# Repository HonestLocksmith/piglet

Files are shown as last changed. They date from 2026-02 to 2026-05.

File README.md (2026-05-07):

# Piglet Wardriver

**Piglet** is an open-source ESP32-based wardriving platform that scans nearby Wi-Fi networks, records GPS position, saves WiGLE-compatible CSV logs to SD, and provides a real-time web UI for control, uploads, and device status.

Designed for **Seeed XIAO ESP32-S3, ESP32-C5, and ESP32-C6**, Piglet focuses on:

- Reliable scanning while in motion  
- Clean WiGLE-ready data collection  
- Simple field deployment  
- Fully hackable open firmware

## Features

- 2.4 GHz Wi-Fi scanning  
- 5 GHz scanning on ESP32-C5 hardware  
- GPS position, heading, and speed logging  
- SD card logging in WiGLE CSV format  
- Web UI for:
  - Start / stop scanning  
  - Upload logs to WiGLE  
  - View device status  
  - Manage SD files  
  - Edit configuration  
- OLED live status display  
- Optional battery monitoring (board dependent)  
- Automatic STA connect with AP fallback  
- Optimized for mobile wardriving or warWalking!
- **ESP-Now Mesh Node mode** — pair with a coordinator device for multi-node wardriving
- **Mesh auto-start on boot** — configure `meshModeOnBoot` to automatically enter Core or Node mode after uploads complete, bypassing the AP window

## ESP-Now Mesh Network Node Mode

Piglet includes a built-in **Mesh Node mode** that lets it act as a wireless wardriving node alongside a compatible coordinator device. In this mode, Piglet scans Wi-Fi networks and forwards results over ESP-Now — no SD card or GPS fix required on Piglet itself. The coordinator handles GPS stamping and data logging.

### Compatible Coordinator Devices

- **Biscuit Pro** by [Hedge / Biscuit Shop](https://biscuitshop.us)
- **JCMK C5 Wardriver** by JustCallMeKoko

### How to Use

1. Power on your coordinator device (Biscuit Pro or JCMK C5 Wardriver)
2. On Piglet, press the button to cycle pages until you reach **Mesh Node** (the last page after the pig animation)
3. Piglet automatically searches for a coordinator on ESP-Now channel 6
4. Once connected, it receives a channel range assignment and begins forwarding scan data
5. Press the button again to exit Mesh Node mode and return to normal wardriving

### Mesh Node Display

While in Mesh Node mode the OLED shows:
- Link status (Searching / Core linked)
- Coordinator MAC address
- Assigned channel range
- Total networks discovered
- Records forwarded to the coordinator

> **Note:** Entering Mesh Node mode suspends normal WiGLE CSV logging. All data is sent live to the coordinator. Exiting the page restores normal scanning automatically.

### Auto-Start Mesh Mode on Boot

Set `meshModeOnBoot` in `/wardriver.cfg` to automatically enter mesh mode after boot uploads are complete, without needing to navigate pages manually:

| Value | Behaviour |
|---|---|
| `none` | Normal wardriving (default) |
| `core` | Enters Mesh Core mode — acts as coordinator, logs records from nodes |
| `node` | Enters Mesh Node mode — forwards scan results to a Core |

When `core` or `node` is set the SoftAP window is **skipped entirely** (ESP-Now owns the WiFi stack and the AP would be non-functional). The device goes straight from boot uploads to the mesh page. Set via the web UI **Mesh Mode On Boot** dropdown or directly in `/wardriver.cfg`.

## T-Dongle C5 Variant

A standalone firmware port is available for the **LilyGo T-Dongle C5** in the `TDongleC5_Piglet/` folder. This variant is a self-contained single-file sketch with its own display driver, LED control, and web UI — no external OLED required.

**Hardware:** LilyGo T-Dongle C5 (ESP32-C5, built-in ST7735 0.96" TFT, APA102 LED, TF card slot)

**Additional GPS:** Connect any UART GPS module via the Qwiic/JST connector (RX=GPIO12, TX=GPIO11)

**Pages:** Status · Networks · Navigation · Pig animation · Mesh Node

### T-Dongle C5 Required Libraries

Install via Arduino Library Manager (`Sketch → Include Library → Manage Libraries`):

| Library | Author |
|---|---|
| Adafruit ST7735 and ST7789 Library | Adafruit |
| Adafruit GFX Library | Adafruit |
| Adafruit BusIO | Adafruit |
| TinyGPSPlus | Mikal Hart |
| ArduinoJson | Benoit Blanchon |

All networking, SPI, SD, ESP-Now, and ESP-IDF headers are included in the ESP32 Arduino core — no separate install needed.

**Board setup:** Add `https://espressif.github.io/arduino-esp32/package_esp32_dev_index.json` to Additional Boards Manager URLs, install **esp32 by Espressif v3.x or later**, and select **ESP32C5 Dev Module**.

## Supported Hardware

### Microcontroller Boards

- Seeed XIAO ESP32-S3  
- Seeed XIAO ESP32-C5 *(required for 5 GHz scanning)*  
- Seeed XIAO ESP32-C6  
- LilyGo T-Dongle C5 *(standalone variant — see above)*  

### Required Peripherals

- I2C GPS module (ATGM336H)
- 128×64 SSD1306 OLED display (I2C)
- SPI SD card module
- Optional LiPo battery connected to XIAO battery inputs

### Peripheral Sourcing  
You can get everything on Amazon but its pricey.  if you dont mind waiting on aliexpress heres the build list.
- Xiao-C5 - 7$ [SeedStudio](https://www.seeedstudio.com/Seeed-Studio-XIAO-ESP32C5-p-6609.html)
- SSD1306 128x63 OLED - $2 [aliexpress](https://www.aliexpress.us/item/3256805954920554.html)
- ATGM-336h - $3.39 [aliexpress](https://www.aliexpress.us/item/3256809330278648.html)
- SD-Card Module - $1.33 [aliexpress](https://www.aliexpress.us/item/3256808167816573.html)
- User Button - $0.41 [Item:CS1211 From Digikey](https://www.digikey.com/en/products/detail/cit-relay-and-switch/CS1211/16607858)

$14 if you wanted to breadboard it yourself.

## Wiring / Pinouts

Pin mappings are automatically selected by firmware.

### XIAO ESP32-S3

| Function | Pin |
|---|-----|
| I2C SDA | GPIO 5 |
| I2C SCL | GPIO 6 |
| GPS RX | GPIO 4 |
| GPS TX | GPIO 7 |
| Button | GPIO 1 |
| SD CS | GPIO 2 |
| SD MOSI | GPIO 10 |
| SD MISO | GPIO 9 |
| SD SCK | GPIO 8 |

### XIAO ESP32-C6 / ESP32-C5

| Function | Pin |
|---|-----|
| I2C SDA | GPIO 23 |
| I2C SCL | GPIO 24 |
| GPS RX | GPIO 12 |
| GPS TX | GPIO 11 |
| Button | GPIO 0 |
| SD CS | GPIO 7 |
| SD MOSI | GPIO 10 |
| SD MISO | GPIO 9 |
| SD SCK | GPIO 8 |

**Note:** Only the ESP32-C5 supports 5 GHz Wi-Fi scanning.

## 3D Printed Cases

Print-ready STL files are available in the `Case Files/` directory. These cases are designed specifically for the Piglet PCB and module stack.

### 👏 Case Design by Bread — Breadbox Systems

The Piglet case was designed by **Bread** at [Breadbox Systems](https://breadboxsystems.com). If you print one, please take a moment to **like and boost the design on MakerWorld** — it helps the creator and makes the design easier for others to find.

> **[🖨️ Print the Piglet Wardriver Case on MakerWorld →](https://makerworld.com/en/models/2708429-piglet-wardriver-case#profileId-3000037)**

| File | Description |
|---|---|
| `Piglet Face.STL` | Front panel / lid |
| `Piglet Butt.STL` | Rear enclosure |
| `Piglet Butt with SMA hole.STL` | Rear enclosure with external antenna cutout |
| `Piglet Midboard.STL` | Internal standoff / mid-layer |
| `Piglet Features.stl` | Feature plate / accessory mount |

For the **T-Dongle C5** variant, GPS antenna mount STLs are included in `TDongleC5_Piglet/GPS STL/`.

> Print with standard PLA or PETG. No supports required on most parts. Recommend 0.2 mm layer height, 3 perimeters.

## PCB Design

Piglet includes custom PCB designs for compact, production-ready builds. KiCad project files and Gerber production files are available in the `PCB Files/` directory.

### PCB Images

| Board Front | Board Back | Board Close-up |
|---|---|---|
| Board1 | Board2 | Board3 |

### Assembled Piglet

| Module Arrangement | Front View | Back View |
|---|---|---|
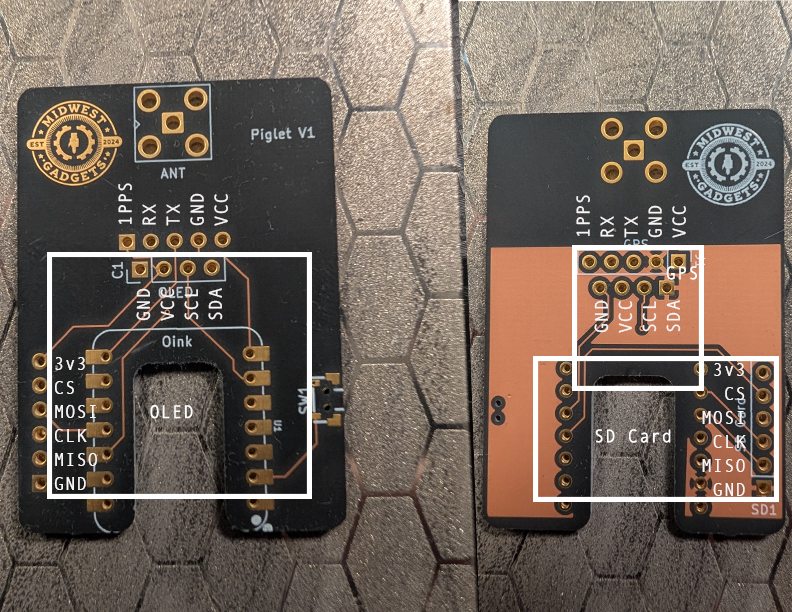
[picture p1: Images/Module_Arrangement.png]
Module Arrangement
|  | Built Piglet Front | Built Piglet Back |

**Assembly Note:** When stacking modules, apply **Kapton tape** between components to prevent electrical shorts. Pay special attention to exposed pins and solder joints that may contact adjacent modules.

## First Time Run Initialization

The Wardriver functions using a config file located on the root of a FAT32-formatted SD card. On first boot the device will start its own access point (`Piglet-WARDRIVE` / `wardrive1234`) so you can connect and fill in your settings via the web interface — or you can place the config file on the SD card manually before powering on.

**AP Timer & Keep-Alive**

The SoftAP runs for **60 seconds** by default. About **30 seconds before** that window expires, the WebUI shows a *"Stay in WebUI?"* prompt — clicking **Stay** extends the window to a **5 minute** rolling timer so you have room to actually use the WebUI. The same prompt re-appears 30 seconds before the 5 minute timer expires; clicking Stay again resets it.

- **Stay** — extends (or re-extends) the window to 5 minutes.
- **Start Scanning Now** — closes the AP immediately and begins wardriving.
- **Ignored / browser closed** — timer runs out, AP closes, scanning starts.

The OLED shows the live countdown (`AP: 192.168.4.1 60s` initially, `m:ss` once extended). Once your home Wi-Fi is configured, the device will connect to it on subsequent boots and the WebUI is reachable on the STA IP shown on the OLED — the AP only comes up if STA fails.

**Location:** `/wardriver.cfg` on the SD card root

A sample config file is included in `Arduino Files/Piglet/wardriver.cfg`. The full default config with all available keys is shown below:

```ini
# ============================================================
# Piglet Wardriver Configuration
# Format: key=value
# Lines starting with # are comments and ignored.
# ============================================================

# ------------------------------------------------------------
# WiGLE Upload
# ------------------------------------------------------------
# Use only the "Encoded for Use" token from wigle.net/account
# Leave empty to disable WiGLE uploads.

wigleBasicToken=EnterWigleTokenHere

# ------------------------------------------------------------
# WDGoWars
# ------------------------------------------------------------
# Get your API key at: https://wdgwars.pl/profile/
# Leave empty to disable WDGoWars uploads.

wdgwarsApiKey=EnterWDGoWarsAPIKeyHere

# ------------------------------------------------------------
# Max Automatic Uploads at Boot
# ------------------------------------------------------------
# -1 = Upload ALL pending files every boot
#  0 = Disabled — no auto-upload at boot (use web UI manually)
# 1+ = Upload up to N files per boot

maxBootUploads=-1

# ------------------------------------------------------------
# Device Name (optional)
# ------------------------------------------------------------
# A short label for this device. Used in WiGLE CSV filenames
# and in the WiGLE upload header so you can tell devices apart.
# Spaces become underscores. Max 20 characters.
# Leave empty to use the default (no prefix).

deviceName=

# ------------------------------------------------------------
# Home Wi-Fi (STA mode)
# ------------------------------------------------------------
# If provided, device connects on boot.
# If connection fails, falls back to SoftAP for 60 seconds
# (can be extended via the "Stay in WebUI?" prompt that appears
# ~30 s before the timer expires).

homeSsid=EnterWifiHere
homePsk=EnterWifiPasswordHere

# ------------------------------------------------------------
# Wardriver Access Point (SoftAP fallback)
# ------------------------------------------------------------
# SSID and password for the temporary config AP.
# Password must be 8+ characters or AP becomes open.

wardriverSsid=Piglet-WARDRIVE
wardriverPsk=wardrive1234

# ------------------------------------------------------------
# GPS Settings
# ------------------------------------------------------------
# UART baud rate for the GPS module.
# Common values: 9600, 38400, 115200

gpsBaud=9600

# ------------------------------------------------------------
# Wi-Fi Scan Mode
# ------------------------------------------------------------
# aggressive  — scans every ~3 seconds using async mode (faster, more power)
# powersaving — scans every ~12 seconds (slower, less power)

scanMode=aggressive

# ------------------------------------------------------------
# Speed Units (display only)
# ------------------------------------------------------------
# kmh = kilometers per hour
# mph = miles per hour

speedUnits=mph

# ------------------------------------------------------------
# Battery Test
# ------------------------------------------------------------
# true = logs elapsed time on battery to /battery_test.csv
# false = disabled

batteryTest=false

# ------------------------------------------------------------
# Mesh Mode On Boot
# ------------------------------------------------------------
# Automatically enter ESP-Now mesh mode after boot uploads complete.
# Bypasses the SoftAP window and jumps directly to the mesh page.
#
#   none = Normal wardriving mode (default)
#   core = Start as Mesh Core (coordinator) — logs data from nodes
#   node = Start as Mesh Node — forwards scan results to a Core
#
# Requires a compatible coordinator (Biscuit Pro, JCMK C5 Wardriver)
# when using node mode.

meshModeOnBoot=none
```

## Button Functions

### Press Types

| Press | Timing | Action |
|---|---|---|
| **Single press** | Quick tap | Advance to next page |
| **Double press** | Two taps within 350 ms | Toggle scan pause *(Status page only)* |
| **Long press** | Hold ≥ 2 seconds | Enter deep sleep |
| **Single press** *(while sleeping)* | Any | Wake from deep sleep / reboot |

### Pages (Single Press cycles through these)

| Page | Name | What it Shows | Scanning |
|---|---|---|---|
| 0 | **Status** | Scan state, SD, GPS fix, WiFi, network counts, speed, IP, upload status | ✅ Active |
| 1 | **Networks** | Large display of 2.4 GHz, 5 GHz, and total network counts | ✅ Active |
| 2 | **Navigation** | Compass arrow, heading direction, current speed | ✅ Active |
| 3 | **Paused** | Pause icon — scanning fully stopped | ❌ Paused |
| 4 | **Pig** | Walking pig animation 🐷 | ✅ Active |
| 5 | **Mesh Node** | ESP-Now link state, coordinator MAC, channel range, Found/Sent counts | ↔ Forwarded via ESP-Now |

### Double Press — Status Page Only

When on the **Status page**, double-pressing toggles a scan pause without leaving the page. Useful for a quick stop without navigating to the Pause page.

- **Double press →** Scanning paused on status page
- **Double press again →** Scanning resumed
- **Single press (page change) →** Pause automatically cleared when leaving page 0

### Long Press — Deep Sleep

Hold the button for **2 seconds** from any page:
- Active log file is flushed and closed before sleeping
- OLED displays `Sleep...` then powers off
- A single button press wakes the device (full reboot)

### Mesh Node Page

Entering **page 5** automatically starts ESP-Now node mode. Leaving it (single press to advance) automatically restores normal wardriving. See the [ESP-Now Mesh Network Node Mode](#esp-now-mesh-network-node-mode) section above for details.

## Building Firmware

### Requirements

- **Arduino IDE 2.x** or **PlatformIO**
- **Arduino-ESP32 core** v3.0.0 or later

### Required Libraries — XIAO Variant (S3 / C5 / C6)

Install via Arduino Library Manager (`Sketch → Include Library → Manage Libraries`):

| Library | Author | Notes |
|---|---|---|
| TinyGPSPlus | Mikal Hart | GPS NMEA parsing |
| Adafruit GFX Library | Adafruit | Graphics dependency |
| Adafruit SSD1306 | Adafruit | OLED display driver |
| Adafruit BusIO | Adafruit | Required by SSD1306 |
| ArduinoJson | Benoit Blanchon | v6.x or v7.x |

All other headers (`WiFi`, `WebServer`, `WiFiClientSecure`, `HTTPClient`, `SD`, `SPI`, `Wire`, `esp_now.h`, `esp_wifi.h`) are included in the ESP32 Arduino core — no separate install needed.

### Required Libraries — T-Dongle C5 Variant

Install via Arduino Library Manager:

| Library | Author | Notes |
|---|---|---|
| Adafruit ST7735 and ST7789 Library | Adafruit | TFT display driver |
| Adafruit GFX Library | Adafruit | Graphics dependency |
| Adafruit BusIO | Adafruit | Required by ST7735 |
| TinyGPSPlus | Mikal Hart | GPS NMEA parsing |
| ArduinoJson | Benoit Blanchon | v6.x or v7.x |

All networking, SPI, SD, ESP-Now, and ESP-IDF headers are built into the ESP32 core.

### Flash Steps

1. Select the correct **XIAO ESP32 board** variant (S3, C5, or C6)
2. **CRITICAL:** Enable **PSRAM** (required for TLS/HTTPS uploads)
   - Tools → PSRAM → **OPI PSRAM** (C5/C6) or **QSPI PSRAM** (S3)
3. Use a **large app partition scheme** → **Huge APP (3MB No OTA/1MB SPIFFS)**
4. Upload firmware  
5. Insert **FAT32-formatted SD card**  
6. Add `/wardriver.cfg` to SD card root with your WiGLE API key and WiFi credentials
7. Restart device with RST button or power cycle

## License

Creative Commons Attribution-NonCommercial 4.0 (CC BY-NC 4.0)

You may:

- Use  
- Modify  
- Share  

You may **not** use this project for commercial purposes.

https://creativecommons.org/licenses/by-nc/4.0/

---

Created by **Midwewest Gadgets LLC**

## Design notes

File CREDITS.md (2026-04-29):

# Credits & Attributions

Piglet Wardriver is licensed under [CC BY-NC-SA 4.0](LICENSE).  
The following third-party work, protocols, and contributions are acknowledged below.

---

## ESP-Now Mesh Protocol

**Project:** ESP32 Dual Band Wardriver  
**Author:** JustCallMeKoko ([@justcallmekoko](https://github.com/justcallmekoko))  
**Repository:** https://github.com/justcallmekoko/ESP32DualBandWardriver

Piglet's **Mesh Node mode** (page 5 on XIAO, page 4 on T-Dongle C5) implements a
wire-compatible version of the JCMK ESP-Now Core/Node protocol. This allows Piglet
to act as a scan node alongside JustCallMeKoko's coordinator hardware.

The protocol constants, message type values, and wire format used in Piglet's
`MeshNode.h` / `MeshNode.cpp` (XIAO) and the mesh section of `TDongleC5_Piglet.ino`
are derived from and designed for compatibility with the JCMK wardriver protocol.
The C++ implementation within Piglet is original work.

Full credit to JustCallMeKoko for designing the open ESP-Now mesh protocol that
makes multi-node wardriving interoperable.

---

## AP Keep-Alive WebUI Feature

**Contributor:** dagnazty ([@dagnazty](https://github.com/dagnazty))  
**Pull Request:** [#3](https://github.com/Hamspiced/piglet/pull/3)

The SoftAP keep-alive modal ("Stay in WebUI?" prompt) — including the `/extend`
endpoint, extended 5-minute rolling window, and client-side countdown timer — was
contributed by dagnazty and merged in v2.2.

---

## Project

**Author:** Midwest Gadgets LLC  
**License:** CC BY-NC-SA 4.0 — https://creativecommons.org/licenses/by-nc-sa/4.0/

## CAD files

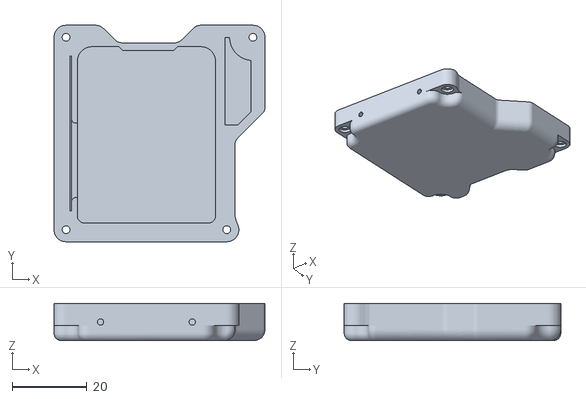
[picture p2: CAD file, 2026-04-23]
Case Files/Piglet Butt.STL
56.6 x 58.1 x 10.0

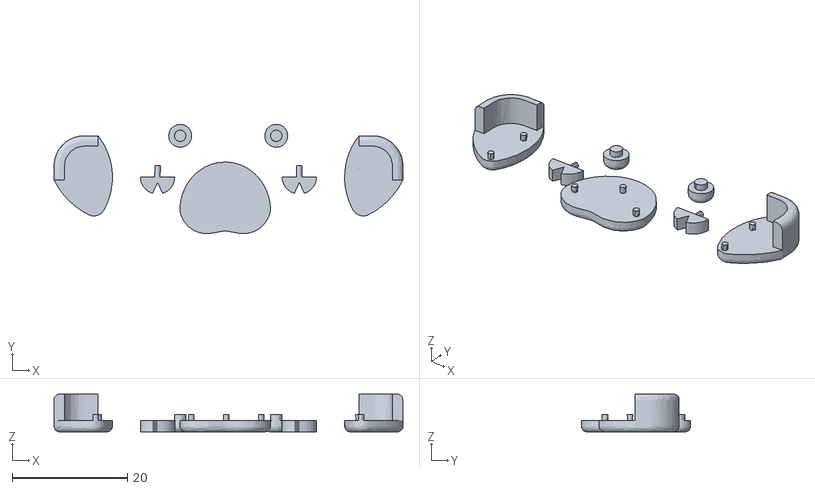
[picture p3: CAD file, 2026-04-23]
Case Files/Piglet Features.stl
60.6 x 19.0 x 6.57

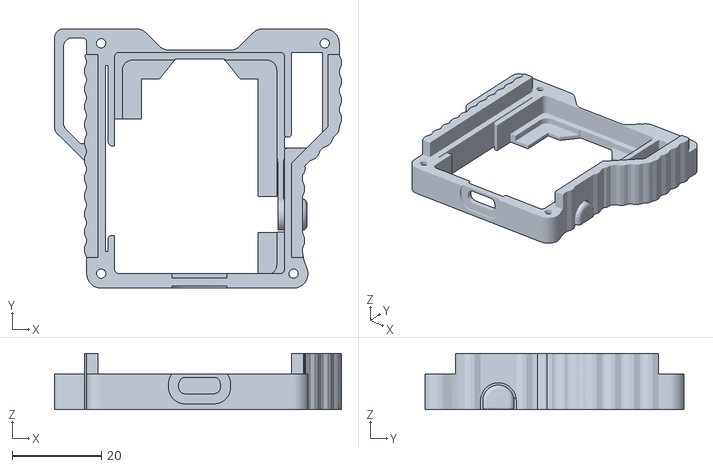
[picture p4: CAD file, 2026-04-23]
Case Files/Piglet Midboard.STL
64.3 x 58.1 x 12.6

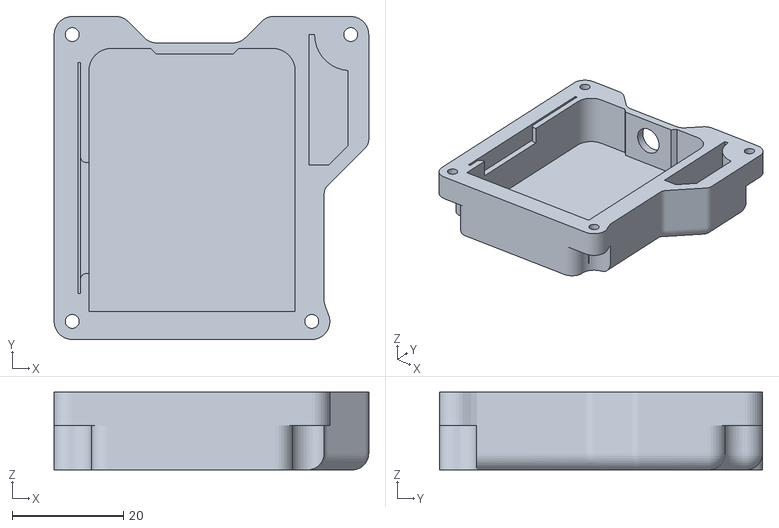
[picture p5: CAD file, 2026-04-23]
Case Files/Piglet Butt with SMA hole.STL
56.6 x 58.1 x 14.0

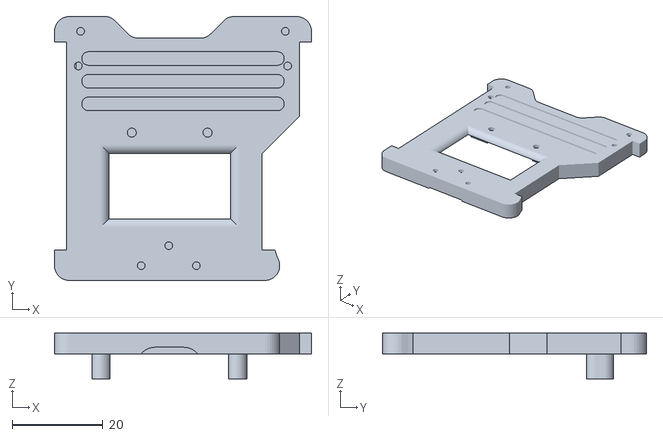
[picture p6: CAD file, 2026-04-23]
Case Files/Piglet Face.STL
56.6 x 58.1 x 10.1

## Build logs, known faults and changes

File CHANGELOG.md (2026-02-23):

# Changelog

## v1.3-beta (2026-02-23)

### New Features
- **WiGLE Upload History Tracking**: Web UI now displays upload statistics (new networks discovered, total networks) for uploaded files
- **Automatic Boot Upload with Quota Management**: Configurable `maxBootUploads` setting (default: 25) to control how many files upload automatically at boot
- **24-Hour History Caching**: Upload history API calls are cached for 24 hours to conserve WiGLE API quota (25 calls/day limit)
- **On-Demand History Refresh**: History automatically refreshes in web UI when cache expires (only when connected to home network)

### Improvements
- **Optimized Upload Performance**: Removed token pre-checks and reduced timeouts for faster batch uploads
- **Enhanced WiFi Stability**: Scanning now properly pauses when connected to home network to prevent connection drops
- **Web Server Startup Timing**: Web server now starts after WiGLE operations complete to avoid resource conflicts
- **Improved Configuration Management**: Added `maxBootUploads` and `speedUnits` configuration options
- **Better Status Display**: Config form in web UI now properly displays all saved values including WiGLE token

### Bug Fixes
- Fixed scanning interference causing 100% ping loss when connected to home WiFi
- Fixed web UI configuration display issues (all fields now populate correctly)
- Fixed chunked encoding errors in `/status.json` and `/files.json` endpoints
- Corrected WiGLE token display (now shows actual token instead of "(set)")
- Fixed JSON buffer overflow issues in files endpoint

### Technical Changes
- Increased JSON buffer for files endpoint from 4KB to 8KB to handle upload statistics
- Switched from HTTP/1.1 to HTTP/1.0 for WiGLE API compatibility
- Added proper `client.flush()` to ensure complete data transmission
- Reduced upload timeout from 60s to 25s for better reliability
- History parsing now uses incremental JSON parsing to reduce memory fragmentation

### Configuration
- New config option: `maxBootUploads` - Max CSV files to upload at boot (0-25, default: 25)
- Updated config option: `speedUnits` - Display speed in km/h or mph
- Config file now saves `maxBootUploads` setting to `/wardriver.cfg`

### Requirements
- **CRITICAL**: PSRAM must be enabled in Arduino IDE for reliable TLS/HTTPS uploads
  - ESP32-C5/C6: Use OPI PSRAM
  - ESP32-S3: Use QSPI PSRAM
- Arduino-ESP32 core v3.0.0 or later
- Updated library dependencies documented in README

### Known Issues
- ESP32-C5/C6 require PSRAM enabled or TLS connections will fail due to insufficient heap
- Initial boot may show "Failed to allocate dummy cacheline for PSRAM" warning (can be ignored)

### Migration Notes
- No breaking changes from v1.2
- Existing `/wardriver.cfg` files are compatible
- New `maxBootUploads` setting will default to 25 if not present in config

---

## v1.2 (Previous Release)
- Initial stable release with basic wardriving functionality
- SD card CSV logging
- Web UI for file management
- Manual WiGLE upload support

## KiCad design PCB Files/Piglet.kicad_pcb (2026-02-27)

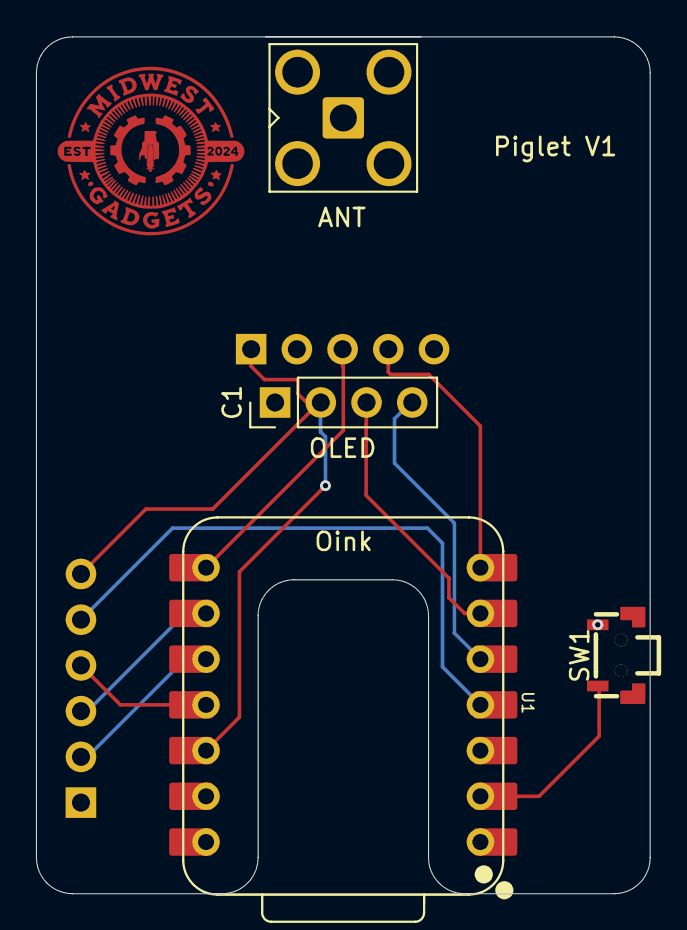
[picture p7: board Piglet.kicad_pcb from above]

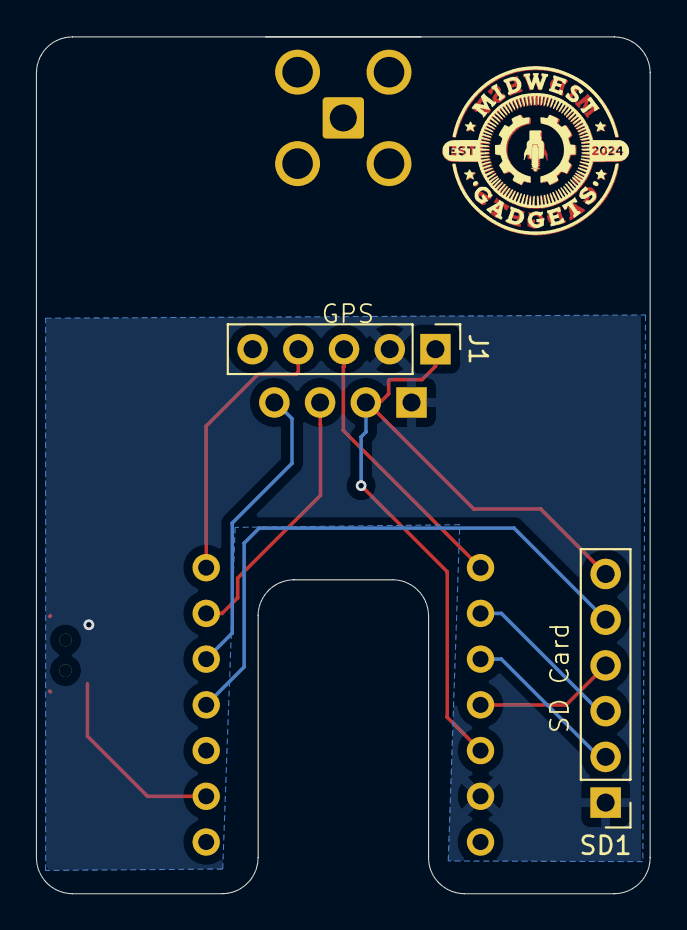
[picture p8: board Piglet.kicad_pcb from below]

Board: 2 copper layers, 34.1 x 47.6 mm, 6 parts (2 on the bottom side), 11 nets.

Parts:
ANT: SMA_Amphenol_901-143_Horizontal
C1: SSD1306 128x64; PinHeader_1x04_P2.54mm_Vertical
J1: Conn_01x05_Pin; PinHeader_1x05_P2.54mm_Vertical
SD1: Conn_01x06_Pin; PinHeader_1x06_P2.54mm_Vertical
SW1: SW_Push; SW-SMD_TS24CA
U1: XIAO-ESP32-C6-SMD; XIAO-ESP32-C6-DIP

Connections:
+3V3: C1.2 (VCC), J1.5, SD1.6, U1.12 (3V3)
CS: SD1.5, U1.4 (GPIO21_D3)
D1: SW1.1, U1.2 (GPIO1_A1_D1)
GND: C1.1 (GND), J1.4, SD1.1, SW1.2, U1.13 (GND)
Mosi: SD1.4, U1.11 (GPIO18_D10_MOSI)
RX: J1.2, U1.7 (GPIO16_D6_TX)
TX: J1.3, U1.8 (GPIO17_D7_RX)
clk: SD1.3, U1.9 (GPIO19_D8_SCK)
miso: SD1.2, U1.10 (GPIO20_D9_MISO)
scl: C1.3 (SCL), U1.6 (GPIO23_D5_SCL)
sda: C1.4 (SDA), U1.5 (GPIO22_D4_SDA)

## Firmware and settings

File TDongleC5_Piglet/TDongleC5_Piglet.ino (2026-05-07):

/*
 * LilyGo T-Dongle C5 Piglet Wardriver
 * (WiGLE CSV + GPS + SD + TFT + Web UI + APA102 LED)
 *
 * STANDALONE PORT — single-file sketch for the T-Dongle C5 board.
 * ESP32-C5 with dual-band Wi-Fi 6 (2.4 + 5 GHz), ST7735 0.96" TFT, TF card, APA102 LED.
 *
 * Pin Map (T-Dongle C5):
 *   LCD (ST7735, SPI):
 *     MOSI = GPIO2, SCK = GPIO6, CS = GPIO10, DC = GPIO3, RST = GPIO1, BL = GPIO0
 *   SD / TF (shared SPI):
 *     CS = GPIO23, SCK = GPIO6, MISO = GPIO7, MOSI = GPIO2
 *   APA102 LED (shared SPI):
 *     DI = GPIO2, CI = GPIO7  (bit-bang when LCD+SD deselected)
 *   GPS (UART via Qwiic/JST connector):
 *     RX = GPIO12, TX = GPIO11
 *   Button:
 *     BOOT = GPIO9 (INPUT_PULLUP, strapping pin — safe to use as GPIO after boot)
 *
 * License: CC BY-NC-SA 4.0
 */

#include <Arduino.h>
#include <WiFi.h>
#include <WebServer.h>
#include <HTTPClient.h>
#include <WiFiClientSecure.h>
#include <SPI.h>
#include <SD.h>
#include <sys/time.h>
#include <ArduinoJson.h>
#include <TinyGPSPlus.h>

#include <stdint.h>
#include "esp_netif.h"
#include <vector>
#include <time.h>
#include <math.h>
#include <esp_now.h>
#include "esp_wifi.h"

// Firmware version
#define FIRMWARE_VERSION "v2.3"

// ---------------- Pins (T-DONGLE C5) ----------------
struct PinMap {
  // TFT (SPI)
  int tft_sck, tft_mosi, tft_cs, tft_dc, tft_rst, tft_bl;
  // SD (SPI - shared bus)
  int sd_cs, sd_sck, sd_miso, sd_mosi;
  // APA102 LED (bit-bang)
  int led_di, led_ci;
  // GPS (UART via Qwiic)
  int gps_rx, gps_tx;
  // User button
  int btn;
};

static const PinMap PINS = {
  // TFT
  6,   // tft_sck
  2,   // tft_mosi
  10,  // tft_cs
  3,   // tft_dc
  1,   // tft_rst
  0,   // tft_bl
  // SD (shares SCK/MOSI with TFT)
  23,  // sd_cs
  6,   // sd_sck
  7,   // sd_miso
  2,   // sd_mosi
  // APA102 LED
  2,   // led_di  (shared with MOSI)
  7,   // led_ci  (shared with MISO)
  // GPS (Qwiic/JST connector)
  12,  // gps_rx
  11,  // gps_tx
  // BTN (user button on GPIO28 — confirmed by board hardware)
  28
};

// ---------------- TFT (Adafruit ST7735 — works on ESP32-C5) ----------------
#include <Adafruit_GFX.h>
#include <Adafruit_ST7735.h>

// Subclass to expose protected setColRowStart (became protected in library v1.10+)
class Adafruit_ST7735Ex : public Adafruit_ST7735 {
public:
  Adafruit_ST7735Ex(int8_t cs, int8_t dc, int8_t rst) : Adafruit_ST7735(cs, dc, rst) {}
  void setColRowStartPublic(int8_t col, int8_t row) { setColRowStart(col, row); }
};

// Use the hardware SPI constructor with CS, DC, RST
static Adafruit_ST7735Ex tft(PINS.tft_cs, PINS.tft_dc, PINS.tft_rst);

// RGB565 colors
#define COLOR_RED    ST77XX_RED
#define COLOR_GREEN  ST77XX_GREEN
#define COLOR_BLUE   ST77XX_BLUE
#define COLOR_CYAN   ST77XX_CYAN
#define COLOR_YELLOW ST77XX_YELLOW
#ifndef BLACK
  #define BLACK ST77XX_BLACK
#endif
#ifndef WHITE
  #define WHITE ST77XX_WHITE
#endif

// Adafruit GFX doesn't have textWidth() — calculate from text size
static int tftTextWidth(const char* txt, int textSize = 1) {
  if (!txt) return 0;
  return strlen(txt) * 6 * textSize;  // 6px per char at size 1
}

// ---------------- GPS ----------------
TinyGPSPlus gps;
HardwareSerial GPSSerial(1);

// ---------------- Web ----------------
WebServer server(80);

// ---------------- Config ----------------
struct Config {
  String wigleBasicToken;
  String homeSsid;
  String homePsk;
  String wardriverSsid = "Piglet-WARDRIVE";
  String wardriverPsk  = "wardrive1234";
  uint32_t gpsBaud     = 9600;
  String scanMode      = "aggressive";
  String speedUnits    = "kmh";
  // WDGoWars API key from https://wdgwars.pl/profile
  String wdgwarsApiKey;
  // Boot auto-upload limit: -1=all, 0=disabled, 1+=capped
  int maxBootUploads   = 25;
  // Optional device name shown in WiGLE header and filename
  String deviceName;
  // Auto-start mesh role on boot: "core" | "node" | "none"
  String meshModeOnBoot = "none";
};

Config cfg;
static const char* bootSlogan = nullptr;

// ---------------- State ----------------
static bool sdOk = false;
static bool scanningEnabled = true;
static bool gpsHasFix = false;

// UI state
static int   uiGpsSats    = 0;
static float uiHeadingDeg = 0.0f;
static String uiHeadingTxt = "—";
static bool uiFirstDraw = true;

// Diff-repaint cache
static bool     prevAllowScan = false;
static bool     prevSdOk = false;
static bool     prevGpsFix = false;
static bool     prevSta = false;
static uint32_t prevFound2G = 0;
static uint32_t prevFound5G = 0;
static float    prevSpeed = -999;
static String   prevIp = "";
static String   prevUploadMsg = "";
static uint32_t prevUploadDone = 0;
static uint32_t prevUploadTotal = 0;

// Scan control
static bool userScanOverride = false;
static bool autoPaused = false;

// AP window
static uint32_t apStartMs = 0;
static bool apClientSeen = false;
static bool apWindowActive = false;
static const uint32_t AP_WINDOW_MS = 60000UL;

// Extended AP window — 5 min rolling timer, driven by the WebUI keep-alive modal
static bool     apExtended           = false;
static uint32_t apExtendedStartMs    = 0;
static bool     apForceClose         = false;
static const uint32_t AP_EXTENDED_WINDOW_MS    = 5UL * 60UL * 1000UL; // 5 minutes
static const uint32_t AP_EXTEND_PROMPT_LEAD_MS = 30000UL;              // prompt 30 s before expiry

// Counters
static uint32_t networksFound2G = 0;
static uint32_t networksFound5G = 0;

// Log state
static File logFile;
static String currentCsvPath;
static wl_status_t lastStaStatus = WL_IDLE_STATUS;

// ---------------- Upload State ----------------
static bool     uploading = false;
static bool     uploadPausedScanWasEnabled = false;
static uint32_t uploadTotalFiles = 0;
static uint32_t uploadDoneFiles  = 0;
static uint32_t uploadFailedFiles = 0;
static String   uploadCurrentFile = "";
static String   uploadLastResult  = "";
static String   uploadTargetName  = "";  // shown on TFT during upload
static int      wigleTokenStatus  = 0;
static int      wigleLastHttpCode = 0;

static const char* WDGWARS_HOST = "wdgwars.pl";
static const uint16_t WDGWARS_PORT = 443;

static const char* WIGLE_HOST = "api.wigle.net";
static const uint16_t WIGLE_PORT = 443;

// ---------------- Screen pages ----------------
// Pages: 0=status  1=networks  2=nav  3=pig  4=mesh-node
struct PigState_t {
  int16_t  x       = 0;
  int16_t  y       = 82;   // fixed vertical position in body area
  int8_t   dx      = 1;
  uint8_t  phase   = 0;
  uint32_t lastMs  = 0;
  uint16_t frameMs = 90;
};
static PigState_t    pig;
static uint8_t       currentPage = 0;
static const uint8_t PAGE_COUNT  = 5;
// Set true on page entry so the draw function does a full initial layout.
static bool pageNeedsInit[PAGE_COUNT] = { false, true, true, true, true };

// Navigation page — hold last good heading for HEADING_HOLD_MS after fix is lost
static double        lastGoodHeadingDeg = NAN;
static uint32_t      lastGoodHeadingMs  = 0;
static const uint32_t HEADING_HOLD_MS        = 5000;
static const float    HEADING_MIN_SPEED_KMPH = 3.0f;

// ---------------- APA102 LED (bit-bang) ----------------
// Drives the APA102 RGB LED by bit-banging when LCD+SD are deselected.
// APA102 protocol: 4 bytes start frame (0x00), then 0xE0|brightness, B, G, R, then end frame.

static void apa102Write(uint8_t r, uint8_t g, uint8_t b, uint8_t brightness = 8) {
  // Deselect LCD and SD first
  digitalWrite(PINS.tft_cs, HIGH);
  digitalWrite(PINS.sd_cs, HIGH);

  // Temporarily take over the data/clock pins
  pinMode(PINS.led_di, OUTPUT);
  pinMode(PINS.led_ci, OUTPUT);

  auto sendByte = [](uint8_t val) {
    for (int i = 7; i >= 0; i--) {
      digitalWrite(PINS.led_di, (val >> i) & 1);
      digitalWrite(PINS.led_ci, HIGH);
      delayMicroseconds(1);
      digitalWrite(PINS.led_ci, LOW);
      delayMicroseconds(1);
    }
  };

  // Start frame: 32 bits of 0
  for (int i = 0; i < 4; i++) sendByte(0x00);

  // LED frame: 111xxxxx brightness, blue, green, red
  if (brightness > 31) brightness = 31;
  sendByte(0xE0 | brightness);
  sendByte(b);
  sendByte(g);
  sendByte(r);

  // End frame: 32 bits of 1
  for (int i = 0; i < 4; i++) sendByte(0xFF);

  // Restore SPI peripheral routing — pinMode(OUTPUT) above disconnects pins from the
  // SPI GPIO matrix (gpio_matrix_out sets SIG_GPIO_OUT_IDX). SPI.end()+begin() re-attaches
  // MOSI (GPIO2) and MISO (GPIO7) back to the SPI peripheral.
  SPI.end();
  SPI.begin(PINS.sd_sck, PINS.sd_miso, PINS.sd_mosi);
}

static void ledOff()   { apa102Write(0, 0, 0, 0); }
static void ledGreen() { apa102Write(0, 20, 0, 4); }
static void ledRed()   { apa102Write(20, 0, 0, 4); }
static void ledBlue()  { apa102Write(0, 0, 20, 4); }

// Pulse state for non-blocking LED blink
static uint32_t ledPulseMs = 0;
static void ledPulseGreen() { ledGreen(); ledPulseMs = millis(); }

static void ledTick() {
  if (ledPulseMs && (millis() - ledPulseMs > 80)) {
    ledOff();
    ledPulseMs = 0;
  }
}

// ---------------- Helpers ----------------
static String pathBasename(const String& p) {
  int slash = p.lastIndexOf('/');
  if (slash < 0) return p;
  return p.substring(slash + 1);
}

static String authModeToString(wifi_auth_mode_t m) {
  switch (m) {
    case WIFI_AUTH_OPEN:            return "OPEN";
    case WIFI_AUTH_WEP:             return "WEP";
    case WIFI_AUTH_WPA_PSK:         return "WPA";
    case WIFI_AUTH_WPA2_PSK:        return "WPA2";
    case WIFI_AUTH_WPA_WPA2_PSK:    return "WPAWPA2";
    case WIFI_AUTH_WPA2_ENTERPRISE: return "WPA2EAP";
    case WIFI_AUTH_WPA3_PSK:        return "WPA3";
    case WIFI_AUTH_WPA2_WPA3_PSK:   return "WPA2WPA3";
    default: return "UNKNOWN";
  }
}

static time_t makeUtcEpochFromTm(struct tm* t) {
  const char* oldTz = getenv("TZ");
  setenv("TZ", "UTC0", 1); tzset();
  time_t epoch = mktime(t);
  if (oldTz) setenv("TZ", oldTz, 1); else unsetenv("TZ");
  tzset();
  return epoch;
}

static String iso8601NowUTC() {
  if (gps.date.isValid() && gps.time.isValid() &&
      gps.date.age() < 5000 && gps.time.age() < 5000) {
    char buf[32];
    snprintf(buf, sizeof(buf), "%04d-%02d-%02dT%02d:%02d:%02dZ",
             gps.date.year(), gps.date.month(), gps.date.day(),
             gps.time.hour(), gps.time.minute(), gps.time.second());
    return String(buf);
  }
  uint32_t s = millis() / 1000;
  char buf[32];
  snprintf(buf, sizeof(buf), "1970-01-01T00:%02lu:%02luZ",
           (unsigned long)((s/60)%60), (unsigned long)(s%60));
  return String(buf);
}

// ---------------- Config (plain text key=value) ----------------
static const char* CFG_PATH = "/wardriver.cfg";

static bool parseKeyValueLine(const String& lineIn, String& keyOut, String& valOut) {
  String line = lineIn; line.trim();
  if (line.length() == 0 || line[0] == '#' || line.startsWith("//")) return false;
  int eq = line.indexOf('=');
  if (eq < 0) return false;
  String k = line.substring(0, eq); k.trim();
  String v = line.substring(eq + 1); v.trim();
  if (v.length() >= 2 && ((v[0] == '"' && v[v.length()-1] == '"') ||
      (v[0] == '\'' && v[v.length()-1] == '\''))) {
    v = v.substring(1, v.length()-1); v.trim();
  }
  if (k.length() == 0) return false;
  keyOut = k; valOut = v;
  return true;
}

static void cfgAssignKV(const String& k, const String& v) {
  if (k == "wigleBasicToken") cfg.wigleBasicToken = v;
  else if (k == "homeSsid")      cfg.homeSsid = v;
  else if (k == "homePsk")       cfg.homePsk = v;
  else if (k == "wardriverSsid") cfg.wardriverSsid = v;
  else if (k == "wardriverPsk")  cfg.wardriverPsk = v;
  else if (k == "gpsBaud") { uint32_t b = (uint32_t)v.toInt(); if (b > 0) cfg.gpsBaud = b; }
  else if (k == "scanMode") { if (v == "aggressive" || v == "powersaving") cfg.scanMode = v; }
  else if (k == "speedUnits") { String vv = v; vv.toLowerCase(); if (vv == "kmh" || vv == "mph") cfg.speedUnits = vv; }
  else if (k == "wdgwarsApiKey")   cfg.wdgwarsApiKey = v;
  else if (k == "maxBootUploads") { int n = v.toInt(); if (n >= -1) cfg.maxBootUploads = n; }
  else if (k == "deviceName")      cfg.deviceName = v;
  else if (k == "meshModeOnBoot") { String vv = v; vv.toLowerCase(); if (vv == "core" || vv == "node" || vv == "none") cfg.meshModeOnBoot = vv; }
}

static bool saveConfigToSD() {
  if (!sdOk) return false;
  digitalWrite(PINS.tft_cs, HIGH);
  if (SD.exists(CFG_PATH)) { SD.remove(CFG_PATH); }

  File f = SD.open(CFG_PATH, FILE_WRITE);
  if (!f) return false;

  f.println("# Piglet Wardriver config [T-Dongle C5]");
  f.print("wigleBasicToken="); f.println(cfg.wigleBasicToken);
  f.print("homeSsid=");        f.println(cfg.homeSsid);
  f.print("homePsk=");         f.println(cfg.homePsk);
  f.print("wardriverSsid=");   f.println(cfg.wardriverSsid);
  f.print("wardriverPsk=");    f.println(cfg.wardriverPsk);
  f.print("gpsBaud=");         f.println(cfg.gpsBaud);
  f.print("scanMode=");        f.println(cfg.scanMode);
  f.print("speedUnits=");      f.println(cfg.speedUnits);
  f.print("wdgwarsApiKey=");   f.println(cfg.wdgwarsApiKey);
  f.println("# Boot auto-upload limit: -1=all, 0=disabled, 1+=capped");
  f.print("maxBootUploads=");  f.println(cfg.maxBootUploads);
  f.println("# Device name: shown in WiGLE header and filename (optional)");
  f.print("deviceName=");      f.println(cfg.deviceName);
  f.println("# Mesh mode on boot: core | node | none");
  f.print("meshModeOnBoot=");  f.println(cfg.meshModeOnBoot);

  f.flush(); f.close();
  Serial.println("[CFG] Saved OK");
  return true;
}

static bool loadConfigFromSD() {
  if (!sdOk) return false;
  digitalWrite(PINS.tft_cs, HIGH);
  if (!SD.exists(CFG_PATH)) { Serial.println("[CFG] No config file."); return false; }

  File f = SD.open(CFG_PATH, FILE_READ);
  if (!f) return false;

  while (f.available()) {
    String line = f.readStringUntil('\n');
    String k, v;
    if (parseKeyValueLine(line, k, v)) cfgAssignKV(k, v);
  }
  f.close();

  Serial.println("[CFG] Loaded config:");
  Serial.print("      homeSsid: ");      Serial.println(cfg.homeSsid);
  Serial.print("      gpsBaud: ");       Serial.println(cfg.gpsBaud);
  Serial.print("      scanMode: ");      Serial.println(cfg.scanMode);
  Serial.print("      wigle token: ");   Serial.println(cfg.wigleBasicToken.length() ? "(set)" : "(empty)");
  return true;
}

// ---------------- SD Logging ----------------
static String normalizeSdPath(const char* dir, const char* nameIn) {
  if (!dir || !nameIn) return "";
  String d(dir), n(nameIn);
  d.trim(); n.trim();
  if (d.length() == 0 || n.length() == 0) return "";
  if (d[0] != '/') d = "/" + d;
  while (d.endsWith("/")) d.remove(d.length() - 1);
  if (n[0] == '/') return n;
  String dNoSlash = d;
  if (dNoSlash.startsWith("/")) dNoSlash = dNoSlash.substring(1);
  if (n.startsWith(dNoSlash + "/")) return "/" + n;
  return d + "/" + n;
}

// Sanitise device name for filename/header use
static String tdongleSanitiseName(const String& raw) {
  String s = raw; s.replace(" ", "_");
  for (int i = (int)s.length()-1; i >= 0; i--) {
    char c = s[i];
    if (!isAlphaNumeric(c) && c != '_' && c != '-') s.remove(i, 1);
  }
  if (s.length() > 20) s = s.substring(0, 20);
  return s;
}

static String newCsvFilename() {
  digitalWrite(PINS.tft_cs, HIGH);
  if (!SD.exists("/logs")) SD.mkdir("/logs");
  String prefix = "";
  if (cfg.deviceName.length() > 0) {
    String safe = tdongleSanitiseName(cfg.deviceName);
    if (safe.length() > 0) prefix = safe + "_Piglet-TDongle_";
  }
  for (int tries = 0; tries < 25; tries++) {
    char buf[100];
    snprintf(buf, sizeof(buf), "/logs/%sWiGLE_%lu_%08lX.csv",
             prefix.c_str(), (unsigned long)millis(), (unsigned long)(uint32_t)esp_random());
    String p(buf);
    if (!SD.exists(p)) return p;
  }
  char buf2[100];
  snprintf(buf2, sizeof(buf2), "/logs/%sWiGLE_%lu.csv",
           prefix.c_str(), (unsigned long)millis());
  return String(buf2);
}

static void closeLogFile() {
  if (logFile) {
    digitalWrite(PINS.tft_cs, HIGH);
    logFile.flush();
    logFile.close();
  }
}

static bool openLogFile() {
  if (!sdOk) return false;
  closeLogFile();
  currentCsvPath = newCsvFilename();
  Serial.print("[SD] Opening log: "); Serial.println(currentCsvPath);

  digitalWrite(PINS.tft_cs, HIGH);
  logFile = SD.open(currentCsvPath, FILE_WRITE);
  if (!logFile) return false;

  String deviceField = "Piglet-Wardriver";
  if (cfg.deviceName.length() > 0) {
    String safe = tdongleSanitiseName(cfg.deviceName);
    if (safe.length() > 0) deviceField = "Piglet-TDongle-" + safe;
  }
  logFile.print("WigleWifi-1.4,appRelease=1,model=LilyGo-T-Dongle-C5,release=1,device=");
  logFile.println(deviceField);
  logFile.println("MAC,SSID,AuthMode,FirstSeen,Channel,RSSI,CurrentLatitude,CurrentLongitude,AltitudeMeters,AccuracyMeters,Type");
  logFile.flush();
  return true;
}

static void appendWigleRow(const String& mac, const String& ssid, const String& auth,
                           const String& firstSeen, int channel, int rssi,
                           double lat, double lon, double altM, double accM) {
  if (!sdOk || !logFile) return;

  String safeSsid = ssid;
  safeSsid.replace("\"", "\"\"");

  String line;
  line.reserve(256);
  line += mac; line += ",";
  line += "\""; line += safeSsid; line += "\",";
  line += auth; line += ",";
  line += firstSeen; line += ",";
  line += String(channel); line += ",";
  line += String(rssi); line += ",";
  line += String(lat, 6); line += ",";
  line += String(lon, 6); line += ",";
  line += String(altM, 1); line += ",";
  line += String(accM, 1); line += ",";
  line += "WIFI";

  digitalWrite(PINS.tft_cs, HIGH);
  logFile.println(line);

  static uint32_t lastFlushMs = 0;
  static uint32_t linesSinceFlush = 0;
  linesSinceFlush++;

  if (linesSinceFlush >= 25 || (millis() - lastFlushMs) >= 2000) {
    digitalWrite(PINS.tft_cs, HIGH);
    logFile.flush();
    lastFlushMs = millis();
    linesSinceFlush = 0;
  }
}

// Forward declarations needed by WDGoWars and WiGLE batch functions
static void tftWigleUploadScreen(uint32_t done, uint32_t total, const String& filename);
static void forceStatusFullRedraw();
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
void loop() {
  server.handleClient();

  // AP window
  if (apWindowActive && WiFi.getMode() == WIFI_AP_STA) {
    if (WiFi.softAPgetStationNum() > 0) {
      if (!apClientSeen) Serial.println("[WIFI] AP client connected");
      apClientSeen = true;
    }
  }
  stopAPIfAllowed();

  // GPS
  while (GPSSerial.available()) gps.encode(GPSSerial.read());

  bool prevFix = gpsHasFix;
  gpsHasFix = gps.location.isValid() && gps.location.age() < 2000;
  if (gpsHasFix != prevFix) {
    Serial.println(gpsHasFix ? "[GPS] LOCKED" : "[GPS] NO FIX");
  }

  uiGpsSats = gps.satellites.isValid() ? (int)gps.satellites.value() : 0;

  float speedKmph = gps.speed.isValid() ? gps.speed.kmph() : 0.0f;
  float speedDisplay = (cfg.speedUnits == "mph") ? speedKmph * 0.621371f : speedKmph;

  if (gps.course.isValid() && gps.course.age() < 2000) {
    uiHeadingDeg = gps.course.deg();
    uiHeadingTxt = headingToDir8(uiHeadingDeg);
  }

  // Set system time from GPS (once)
  static bool timeSet = false;
  if (!timeSet && gps.date.isValid() && gps.time.isValid() &&
      gps.date.age() < 5000 && gps.time.age() < 5000) {
    struct tm t {};
    t.tm_year = gps.date.year() - 1900;
    t.tm_mon  = gps.date.month() - 1;
    t.tm_mday = gps.date.day();
    t.tm_hour = gps.time.hour();
    t.tm_min  = gps.time.minute();
    t.tm_sec  = gps.time.second();
    time_t epoch = makeUtcEpochFromTm(&t);
    struct timeval now = { .tv_sec = epoch, .tv_usec = 0 };
    settimeofday(&now, nullptr);
    timeSet = true;
    Serial.println("[TIME] Set from GPS (UTC)");
  }

  pollButton();

  // TFT dispatch — pig ~90 ms, mesh node 1 s, others 500 ms
  if (currentPage == 3) {
    pigAnimTickTFT();
  } else if (currentPage == 4) {
    static uint32_t lastMeshTft = 0;
    if (millis() - lastMeshTft > 1000) {
      lastMeshTft = millis();
      drawPageMeshNode();
    }
  } else {
    static uint32_t lastTft = 0;
    if (millis() - lastTft > 500) {
      lastTft = millis();
      if      (currentPage == 0) updateTFT(speedDisplay);
      else if (currentPage == 1) drawPageNetworks();
      else if (currentPage == 2) drawPageNavigation(speedDisplay);
    }
  }

  // LED tick (non-blocking pulse)
  ledTick();

  handleStaTransitions();

  // Scanning — mesh page handles its own logic; skip normal scan path
  if (currentPage == 4) {
    if (meshCoreActive) coreModeTick();
    else                nodeModeTick();
  } else {
    autoPaused = shouldPauseScanning();
    wifi_mode_t m = WiFi.getMode();
    bool apActive = (m == WIFI_AP || m == WIFI_AP_STA);
    bool allowScan = scanningEnabled && sdOk && !apActive && (userScanOverride || !autoPaused);
    if (allowScan) doScanOnce();
  }

  delay(10);
}

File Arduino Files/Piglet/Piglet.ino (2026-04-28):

/*
 * XIAO ESP32S3 2.4GHz Wardriver (WiGLE CSV + GPS + SD + OLED + Web UI)
 *
 * Features:
 * - 2.4GHz WiFi scan -> WiGLE CSV on SD (append GPS per row)
 * - SSD1306 OLED status
 * - User button toggles scanning on/off
 * - Boot: start SoftAP (192.168.4.1), attempt STA to home WiFi
 * - If STA connects: upload previous CSV files to WiGLE using Basic token
 * - Web UI: browse/download/delete files, edit config (saved to SD)
 * - SoftAP only lasts 60 seconds; then wardrive begins
 *
 * NOTES:
 * - Pins below are for XIAO ESP32-S3 WITHOUT Sense expansion.
 * - WiGLE CSV format: WigleWifi-1.4 header + standard columns.
 */

#include <Arduino.h>
#include <SPI.h>
#include <Wire.h>
#include <sys/time.h>
#include <esp_sleep.h>

#if defined(CONFIG_IDF_TARGET_ESP32S3)
  #include <driver/rtc_io.h>
#endif

#include "Globals.h"
#include "Config.h"
#include "GPS.h"
#include "SDUtils.h"
#include "Display.h"
#include "WiFiManager.h"
#include "Scanner.h"
#include "WigleUpload.h"
#include "WebUI.h"
#include "MeshNode.h"

// -------- Battery Test (uncomment to enable) --------
#include "battery_test.h"

// ---------------- Deep Sleep ----------------
static const uint32_t LONG_PRESS_MS = 2000;

static void enterDeepSleep() {
  Serial.println("[SLEEP] Long press detected – entering deep sleep...");

  // Flush & close the active CSV log
  closeLogFile();

  // Disconnect WiFi cleanly
  WiFi.disconnect(true);
  WiFi.mode(WIFI_OFF);

  // Show message on OLED
  display.clearDisplay();
  display.setTextSize(2);
  display.setTextColor(SSD1306_WHITE);
  display.setCursor(16, 24);
  display.print("Sleep...");
  display.display();
  delay(600);

  // Configure wake source (button press = LOW on INPUT_PULLUP)
  #if defined(CONFIG_IDF_TARGET_ESP32S3)
    rtc_gpio_pullup_en((gpio_num_t)pins.btn);
    rtc_gpio_pulldown_dis((gpio_num_t)pins.btn);
    esp_sleep_enable_ext0_wakeup((gpio_num_t)pins.btn, 0);  // wake on LOW
  #elif defined(CONFIG_IDF_TARGET_ESP32C6) || defined(CONFIG_IDF_TARGET_ESP32C5)
    esp_deep_sleep_enable_gpio_wakeup(1ULL << pins.btn, ESP_GPIO_WAKEUP_GPIO_LOW);
  #else
    esp_sleep_enable_ext0_wakeup((gpio_num_t)pins.btn, 0);  // fallback
  #endif

  // Turn off display
  display.ssd1306_command(SSD1306_DISPLAYOFF);

  Serial.println("[SLEEP] Goodnight.");
  Serial.flush();

  esp_deep_sleep_start();  // never returns – wake triggers reset
}

// ---------------- Button ----------------
static void onPageChange(uint8_t oldPage, uint8_t newPage) {
  if (newPage == 3) {
    Serial.println("[PAGE] Entered pause page -> scanning paused");
  } else if (oldPage == 3) {
    Serial.println("[PAGE] Left pause page -> scanning resumed");
  }

  // Clear status-page pause when leaving page 0
  if (oldPage == 0 && statusPagePaused) {
    statusPagePaused = false;
    Serial.println("[PAGE] Left status page -> status pause cleared");
  }

  // Entering pig page -> reset animation position
  if (newPage == 4) {
    pig.x = 0;
    pig.dx = 1;
    pig.phase = 0;
  }

  // Mesh node page lifecycle
  if (newPage == 5) enterNodeMode();
  if (oldPage == 5) exitNodeMode();

  Serial.print("[PAGE] ");
  Serial.print(oldPage);
  Serial.print(" -> ");
  Serial.println(newPage);
}

static const uint32_t DOUBLE_PRESS_MS = 350;  // max gap between presses for double-press

static void pollButton() {
  static uint32_t lastDebounce = 0;
  static int lastState = HIGH;
  static bool latched = false;
  static uint32_t pressStartMs = 0;
  static bool longPressTriggered = false;

  // Double-press detection
  static uint8_t  clickCount = 0;
  static uint32_t firstClickMs = 0;

  int s = digitalRead(pins.btn);

  if (s != lastState) {
    lastDebounce = millis();
    lastState = s;
  }

  if ((millis() - lastDebounce) > 40) {
    if (s == LOW) {
      if (!latched) {
        pressStartMs = millis();
        longPressTriggered = false;
        latched = true;
      }
      // While held, check for long press
      if (latched && !longPressTriggered &&
          (millis() - pressStartMs >= LONG_PRESS_MS)) {
        longPressTriggered = true;
        clickCount = 0;  // cancel any pending click
        enterDeepSleep();  // never returns
      }
    } else {
      // Released
      if (latched && !longPressTriggered) {
        clickCount++;
        if (clickCount == 1) {
          firstClickMs = millis();
        }
      }
      latched = false;
      longPressTriggered = false;
    }
  }

  // Evaluate click count after double-press window expires
  if (clickCount > 0 && (millis() - firstClickMs) > DOUBLE_PRESS_MS) {
    if (clickCount >= 2 && currentPage == 0) {
      // Double press on status page -> toggle scan pause
      statusPagePaused = !statusPagePaused;
      Serial.print("[BTN] Double press -> status page scan ");
      Serial.println(statusPagePaused ? "PAUSED" : "RESUMED");
    } else {
      // Single press -> cycle page (once, regardless of extra clicks)
      uint8_t oldPage = currentPage;
      currentPage = (currentPage + 1) % PAGE_COUNT;
      onPageChange(oldPage, currentPage);
    }
    clickCount = 0;
  }
}
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

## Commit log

2026-02-20 v1.0-beta: Initial release with modular refactor and new features
    Major Refactor:
    - Split monolithic Piglet.ino (~2970 lines) into 10 module pairs (.h/.cpp)
    - Modules: Globals, Config, Dedup, GPS, SDUtils, Display, WiFiManager, Scanner, WigleUpload, WebUI
    - Slim entry point in Piglet.ino (~393 lines) with setup(), loop(), and button handler
    - Preserved all existing functionality with zero logic changes
    New Features:
    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
    [wardriver.cfg]
2026-02-20 Add .gitignore and remove tracked .DS_Store
    - Ignore .DS_Store, .zip files, and AGENTS.md
    - Remove Arduino Files/.DS_Store from tracking
2026-02-23 Release v1.3-beta: WiGLE upload history, auto-upload quota management, WiFi stability fixes
    - WiGLE upload history tracking with network statistics in web UI
    - Configurable boot auto-upload (maxBootUploads, default: 25)
    - 24-hour history caching to conserve API quota
    - On-demand history refresh when cache expires
    Improvements:
    - Optimized upload performance (removed token pre-checks)
    - Enhanced WiFi stability (scanning pauses when connected)
    - Web server starts after WiGLE operations (prevents conflicts)
    - Better config management and status display
    Bug Fixes:
    - Fixed scanning interference causing connection drops
    - Fixed web UI config display issues
    - Fixed chunked encoding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
    [Config.cpp, Piglet.ino, WigleUpload.cpp]
2026-02-27 v1.4-beta: Add configurable battery test feature
    Features:
    - Battery test now configurable via wardriver.cfg and web UI
    - New 'batteryTest' config option (true/false) to enable/disable elapsed time logging
    - Battery test logs runtime to /battery_test.csv (no battPin dependency required)
    - Enhanced wardriver.cfg with descriptive comments for all config values
    - Organized config file with sections and inline documentation
    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
    [Piglet.kicad_pcb, wardriver.cfg]
2026-03-05 Add PCB and assembly documentation with images
    Added Sections:
    - PCB Design section with board images (Board1-3.jpg)
    - Assembled Piglet section with module arrangement and build photos
    - Assembly note about Kapton tape to prevent shorts
    Images Added:
    - Board1.jpg, Board2.jpg, Board3.jpg (PCB views)
    - Module_Arrangement.png (component layout diagram)
    - BuiltPiglet.jpg, BackBuiltPiglet.jpg (assembled device photos)
2026-04-23 Release 2.0 - Mesh Node mode, T-Dongle C5 variant, 3D printed cases
    ESP-Now Mesh Network Node Mode
    - New page 5 (XIAO) / page 4 (T-Dongle C5) activated after pig animation
    - Compatible with Biscuit Pro by Hedge and JCMK C5 Wardriver as coordinator
    - Broadcasts discovery request on ESP-Now ch 6, accepts channel assignments
    - Scans assigned channel range and forwards BSSID/SSID/security/RSSI records
    - Periodic heartbeat keeps coordinator link alive
    - OLED/TFT shows: link state, coordinator MAC, channel range, found/sent counts
    - Leaving the page does a full WiFi stack reset and resumes normal wardriving
    T-Dongle C5 Variant
    - Standalone single-file sketch for LilyGo T-Dongle C5 in TDongleC5_Pi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
    [Piglet Butt with SMA hole.STL, Piglet Butt.STL, Piglet Face.STL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]
2026-04-27 Fix T-Dongle compile error; add Get API Key links and API key help text
    [TDongleC5_Piglet.ino]
2026-04-27 Update wardriver.cfg: add WDGoWars key, maxBootUploads, improved comments
    [wardriver.cfg]
2026-04-28 Fix web delete stalling and empty CSV cleanup
    - Remove blocking wigleLoadHistory() from handleFiles(); it was making a
    15-second HTTPS call on every file-list and delete request
    - Stamp wigleHistoryLastLoadMs on all failure paths in wigleLoadHistory()
    so failed calls don't keep retrying on every files.json request
    - Add standalone deleteEmptyCsvs() called at every boot to purge header-only
    CSVs regardless of whether uploads are configured
    - Add /cleanup POST endpoint for on-demand empty CSV purge
    - Fix delFile() JS: now awaits loadFiles(), shows Deleting... feedback,
    and surfaces errors instead of silently failing
    - Same fixes applied to T-Dongle C5 variant
    [Piglet.ino, TDongleC5_Piglet.ino, WigleUpload.cpp]
2026-04-28 Fix: move csvHasDataRows before deleteEmptyCsvs (static forward reference)
    [WigleUpload.cpp]
2026-04-29 Add deviceName config key for WiGLE header and filename differentiation
    Both XIAO and T-Dongle C5 variants now support a deviceName= key in
    wardriver.cfg (and the web UI config form).
    When set, the device name:
    - Is appended to the WiGLE CSV header device field:
    XIAO: device=Piglet-{name}
    T-Dongle: device=Piglet-TDongle-{name}
    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
    [wardriver.cfg]
2026-04-30 Fix Core ADMIN delivery: periodic resend + inter-send gap
    When a node is mid-scan (blocking WiFi.scanNetworks across all channels),
    any ESP-Now packet sent by the Core on ch6 is silently dropped. This caused
    the first connected node to retain its 'all channels' assignment after a
    second node joined, since it missed the narrowed-range ADMIN.
    Two fixes:
    1. coreReassignChannels(): add delay(10) between sends to prevent
    back-to-back collisions in the ESP-Now queue.
    2. coreModeTick(): call coreResendAdminToAll() alongside the 5s heartbeat
    so any node that missed the ADMIN while scanning recovers within one cycle.
    [MeshNode.cpp, TDongleC5_Piglet.ino]
2026-04-30 Mesh: 45s node timeout + guaranteed post-scan heartbeat (from JCMK analysis)
    JCMK's ESP32DualBandWardriver uses per-channel async scanning (80ms/ch),
    returning to ch 6 between every channel. Piglet does a blocking scan of
    all 40 channels (~3-5s) which delays the 5s heartbeat timer by the full
    scan duration, leaving only ~2 heartbeat windows in the 20s timeout.
    Short-term fixes from reviewing JCMK's runAdminWindowAfterScanCycle():
    1. CORE_NODE_TIMEOUT: 20s -> 45s to account for blocking scan latency
    2. nodeDoScan(): send a guaranteed heartbeat + reset timer after every
    scan cycle, so the Core always gets one within one scan period
    regardless of timer alignment.
    Long-term: switch to pe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
    [MeshNode.cpp, TDongleC5_Piglet.ino]
2026-04-30 Mesh node: per-channel async scanning (JCMK pattern)
    Replace the blocking WiFi.scanNetworks() full-scan with per-channel
    async scanning matching JCMK's startNextNodeAssignedScan approach:
    - Scan one assigned channel at a time, 80 ms dwell, non-blocking
    - Each loop() call either starts a channel scan or polls for results
    - After completing the full assigned range, enter a 300 ms ch-6 admin
    window: jcmkSetChannel(6) + heartbeat + wait (JCMK runAdminWindowAfterScanCycle)
    - Radio is only off ch 6 for ~80 ms per channel vs. 3-5 s before
    - No more blocking that delayed heartbeats and risked CORE_NODE_TIMEOUT
    - CORE_REQUEST and backup heartbeat timer now guarded against active scan
    - No channel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
    [MeshNode.cpp, TDongleC5_Piglet.ino]
2026-04-30 Fix node scan: return to ch 6 before ESP-Now sends after each channel scan
    After WiFi.scanNetworks(channel=X) completes the radio stays on channel X.
    Calling jcmkSendText() at that point sends on ch X, but the Core only
    listens on ch 6 — so only the ch 6 scan's packets were received, which
    explains why coreRecordsRx incremented but nodes still timed out.
    JCMK always calls setFixedChannel(ESPNOW_CHANNEL) before any ESP-Now
    send (sendBroadcastStringPlain). Apply the same pattern: jcmkSetChannel(6)
    before the jcmkSendText() loop in nodeDoScanTick().
    [MeshNode.cpp, TDongleC5_Piglet.ino]
2026-04-30 Core: register unknown nodes from TEXT/HEARTBEAT (JCMK touchNode pattern)
    The Core was only registering nodes via CORE_REQUEST. If a node already has
    jcmkHaveCore=true (e.g. from a previous session or after Core restart) it
    skips CORE_REQUEST and goes straight to scanning/sending TEXT + heartbeats.
    The Core received those packets (coreRecordsRx going up) but could not match
    them to any active node, so lastHbMs was never updated and nodes timed out.
    Fix: when the Core receives TEXT or HEARTBEAT from an unregistered MAC,
    queue that MAC for registration via the same coreReqBuf path as CORE_REQUEST.
    coreModeTick() then calls coreFindOrAddNode() + coreReassignChannels(),
    sends ADMIN, and the nod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
    [MeshNode.cpp, TDongleC5_Piglet.ino]
2026-04-30 Mesh: broadcast TEXT for better multi-node delivery; CORE_TEXT_QUEUE 16->64
    Two causes of the sent/received mismatch (3941+2113 sent, only 1504 rcvd):
    1. Unicast TEXT with ACK/retry: each jcmkSendText() to jcmkCoreMac waits
    for an ACK. With two nodes bursting records simultaneously, collisions
    cause retries, timeouts and dropped packets. JCMK uses broadcast for
    data in non-encrypted mode (sendBroadcastStringPlain) — no ACK needed,
    both nodes can transmit at the same time. Switch TEXT to JCMK_BCAST.
    Core identifies sender correctly via info->src_addr in the callback.
    2. CORE_TEXT_QUEUE overflow: a single dense channel can produce 20+
    networks. Two nodes flushing at the s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
    [MeshNode.cpp, TDongleC5_Piglet.ino]
2026-04-30 docs: update README and sample configs with meshModeOnBoot
    - README: add meshModeOnBoot to feature list, new Auto-Start Mesh Mode
    section with value table, and key added to the config reference block
    - XIAO wardriver.cfg: add meshModeOnBoot section with comments
    - T-Dongle wardriver.cfg: full rewrite to match XIAO style — adds
    wdgwarsApiKey, maxBootUploads, deviceName, meshModeOnBoot; removes
    invalid board/batteryTest keys that do not apply to the T-Dongle
    [wardriver.cfg]
2026-05-07 docs: remove network de-duplication from features list
2026-05-07 fix: node-mode sends upgraded to full 212-byte packets for Biscuit Pro
    Biscuit Pro (and other Biscuit-family coordinators) use the same
    len < sizeof(enow_text_msg_t) = 212 byte size check in their receive
    callback. Piglet was sending small packets in node mode:
    - jcmkSendCoreRequest: 5 bytes (jcmk_req_msg_t) -> now 212 bytes
    - jcmkSendHeartbeat: 9 bytes (jcmk_hb_msg_t) -> now 212 bytes
    - jcmkSendText: variable 12-212 bytes -> now always 212 bytes
    jcmk_req_msg_t and jcmk_hb_msg_t are replaced with jcmk_text_msg_t
    (zero-initialized) with len=0. JCMK Cores only check len >= 5 so this
    is backward-compatible. Applied to both XIAO and T-Dongle.
    [MeshNode.cpp, TDongleC5_Piglet.ino]
2026-05-07 docs: fix XIAO wardriver.cfg header, add board key, update mesh node comment
    [wardriver.cfg]
2026-05-07 fix: disable auto-reconnect on STA disconnect to unblock WiFi scanning
    When home WiFi was connected at boot (staOk=true), setAutoReconnect was
    never called. After driving out of range the ESP32 WiFi stack silently
    started background reconnection attempts, which ran concurrently with
    WiFi.scanNetworks(). This caused scans to return 0 results while the
    play indicator showed active — displaying zeros and logging nothing.
    Fix: handleStaTransitions() now calls setAutoReconnect(false) +
    WiFi.disconnect(true, false) + WiFi.mode(WIFI_STA) the moment the STA
    connection drops. eraseap=false preserves NVS credentials for the next
    boot upload. Applied to both XIAO (WiFiManager.cpp) and T-Dongle.
    [TDongleC5_Piglet.ino]
